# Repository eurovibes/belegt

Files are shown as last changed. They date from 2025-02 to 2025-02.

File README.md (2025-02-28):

<!-- SPDX-FileCopyrightText: 2025 Benedikt Spranger <b.spranger@linutronix.de> -->
<!-- SPDX-License-Identifier: CERN-OHL-S-2.0 -->


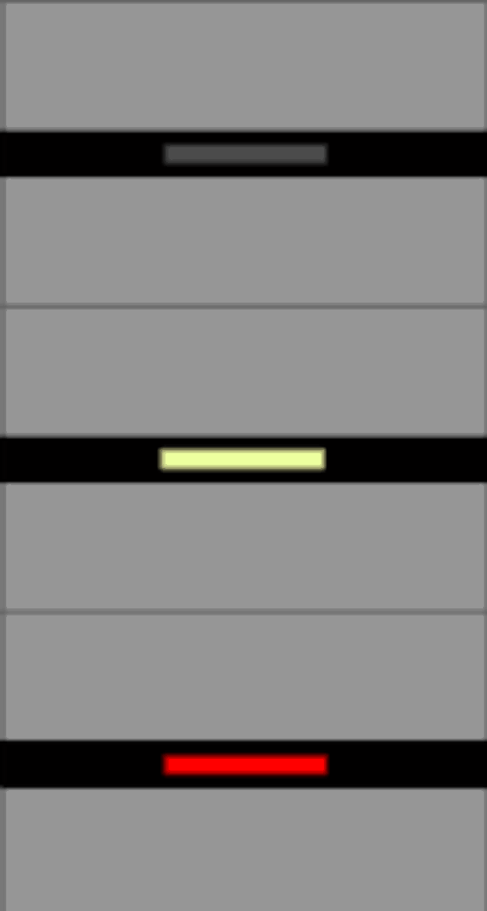
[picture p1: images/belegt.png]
Belegt logo


# Belegt - A model train track occupation sensor

## License rules

belegt is provided under the terms of the CERN-OHL-S license
version 2 as provided in the LICENSES/CERN-OHL-S-2.0 file.

Instead of adding license boilerplates to the individual files,
belegt uses SPDX license identifiers, which are machine parseable
and considered legaly equivalent.

The SPDX license identifier in belegt shall be added at the first
possible line in a file which can contain a comment. This is normally the
first line except for scripts. Scripts require the #!PATH_TO_INTERPRETER tag
in the first line; place the SPDX identifier into the second line.

The SPDX license identifier is added in form of a comment.

## Copyright and License

> Copyright Benedikt Spranger 2023.
> This source describes Open Hardware and is licensed under the CERNOHL-S v2.
> You may redistribute and modify this source and make products using it
> under the terms of the CERN-OHL-S v2 (https://ohwr.org/cern ohl s v2.txt ).
> This source is distributed WITHOUT ANY EXPRESS OR IMPLIED WARRANTY, INCLUDING
> OF MERCHANTABILITY, SATISFACTORY QUALITY AND FITNESS FOR A PARTICULAR PURPOSE.
> Please see the CERN-OHL-S v2 for applicable conditions.
> Source location: https://github.com/eurovibes/belegt
> As per CERN-OHL-S v2 section 4, should You produce hardware based
> on this source, You must where practicable maintain the Source Location
> visible on the external case of the belegt or other products you
> make using this source.

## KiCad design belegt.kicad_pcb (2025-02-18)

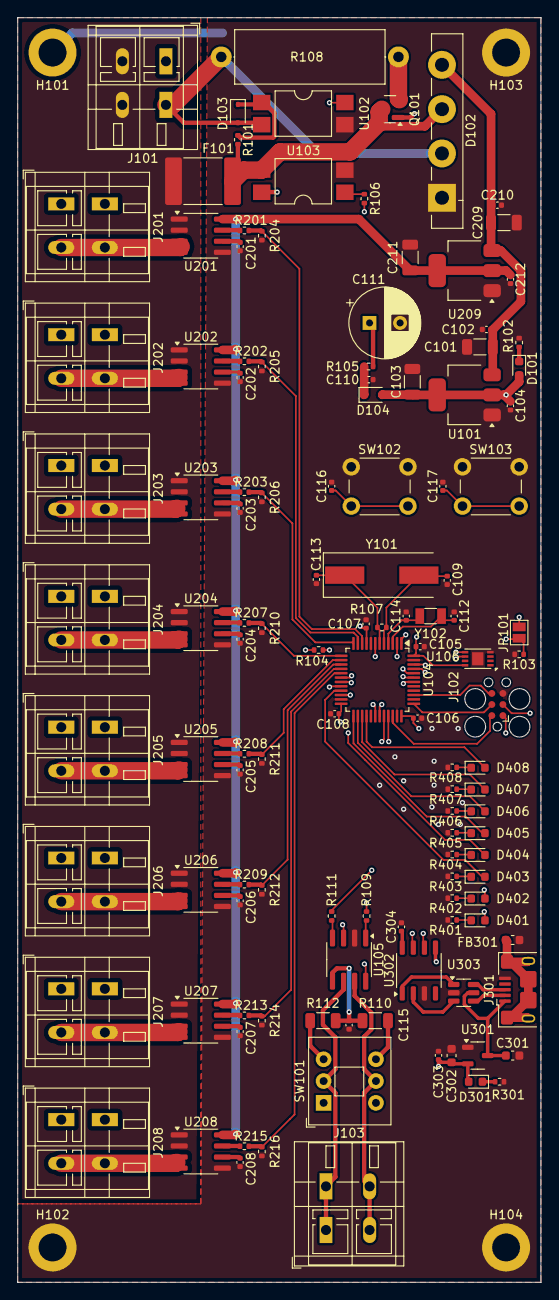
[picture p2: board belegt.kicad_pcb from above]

Board: 4 copper layers, 60.0 x 145.0 mm, 126 parts (0 on the bottom side), 97 nets.

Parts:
C101, C103, C209, C211: 10µ; C_1206_3216Metric
C102, C104, C105, C106, C107, C108, C110, C116, C117, C201, C202, C203, C204, C205, C206, C207, C208, C210, C212, C303, C304: 100n; C_0402_1005Metric
C109, C113: 20p; C_0402_1005Metric
C111: 1F; CP_Radial_D8.0mm_P3.50mm
C112, C114: 12p; C_0402_1005Metric
C115: 4n7; C_0402_1005Metric
C301, C302: 1µ; C_0603_1608Metric
D101, D301, D401, D402, D403, D404, D405, D406, D407, D408: LED; LED_0603_1608Metric
D102: GBU8A; Diode_Bridge_Vishay_GBU
D103, D104: 1N4148WS; D_SOD-323
F101: Polyfuse_Small; Fuse_2920_7451Metric
FB301: FerriteBead_Small; L_0603_1608Metric
H101, H102, H103, H104: MountingHole_3.2mm_M3_ISO14580_Pad
J101: Power IN; TerminalBlock_WAGO_236-402_1x02_P5.00mm_45Degree
J102: Debug; Tag-Connect_TC2030-IDC-FP_2x03_P1.27mm_Vertical
J103: CAN; TerminalBlock_WAGO_236-402_1x02_P5.00mm_45Degree
J201: track1; TerminalBlock_WAGO_236-402_1x02_P5.00mm_45Degree
J202: track5; TerminalBlock_WAGO_236-402_1x02_P5.00mm_45Degree
J203: track7; TerminalBlock_WAGO_236-402_1x02_P5.00mm_45Degree
J204: track2; TerminalBlock_WAGO_236-402_1x02_P5.00mm_45Degree
J205: track6; TerminalBlock_WAGO_236-402_1x02_P5.00mm_45Degree
J206: track8; TerminalBlock_WAGO_236-402_1x02_P5.00mm_45Degree
J207: track3; TerminalBlock_WAGO_236-402_1x02_P5.00mm_45Degree
J208: track4; TerminalBlock_WAGO_236-402_1x02_P5.00mm_45Degree
J301: USB_B_Micro; USB_Micro-B_Amphenol_10118193-0001LF_Horizontal
JP101: Boot0; SolderJumper-2_P1.3mm_Open_Pad1.0x1.5mm
Q101: BC860; SOT-23
R101, R102, R104, R105, R106, R301, R401, R402, R403, R404, R405, R406, R407, R408: 1k; R_0402_1005Metric
R103, R204, R205, R206, R210, R211, R212, R214, R216: 10k; R_0402_1005Metric
R107: 1M; R_0402_1005Metric
R108: 100; R_Axial_DIN0617_L17.0mm_D6.0mm_P20.32mm_Horizontal
R109, R111: 100; R_0402_1005Metric
R110, R112: 60; R_1206_3216Metric
R201, R202, R203, R207, R208, R209, R213, R215: 2k; R_0402_1005Metric
SW101: Term; SW_Push_2P2T_Toggle_CK_PVA2xxH1xxxxxxV2
SW102: Reset; SW_PUSH_6mm
SW103: User; SW_PUSH_6mm
U101: AMS1117-3.3; SOT-223-3_TabPin2
U102, U103: EL817S1(C)(TU)-F; SMDIP-4_W9.53mm
U104: STM32F103CBTx; LQFP-48_7x7mm_P0.5mm
U105: TJA1042T; SOIC-8_3.9x4.9mm_P1.27mm
U106: ATECC608B-MAVDA-S; DFN-8-1EP_3x2mm_P0.5mm_EP1.3x1.5mm
U201, U202, U203, U204, U205, U206, U207, U208: ACS712ELCTR-05B; SOIC-8_3.9x4.9mm_P1.27mm
U209: AMS1117-5.0; SOT-223-3_TabPin2
U301: XC6206P332MR; SOT-23-3
U302: CH340N; SOP-8_3.9x4.9mm_P1.27mm
U303: USBLC6-2SC6; SOT-23-6
Y101: 8MHz; Crystal_SMD_HC49-SD
Y102: 32k; Crystal_SMD_3215-2Pin_3.2x1.5mm

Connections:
+3V3: C103.1, C104.1, C105.1, C106.1, C107.1, C108.1, D101.2 (A), D104.2 (A), J102.1 (VCC), JP101.2 (B), R104.2, U101.2 (VO), U104.9 (VDDA), U104.24 (VDD), U104.36 (VDD), U104.48 (VDD), U105.3 (VCC), U106.8 (VCC)
+5V: C211.1, C212.1, U201.8 (VCC), U202.8 (VCC), U203.8 (VCC), U204.8 (VCC), U205.8 (VCC), U206.8 (VCC), U207.8 (VCC), U208.8 (VCC), U209.2 (VO)
+15V: C101.1, C102.1, C209.1, C210.1, D102.4 (-), U101.3 (VI), U209.3 (VI)
+BATT: C111.1, R105.2, U104.1 (VBAT)
+VSW: F101.1, J101.2, U201.1 (IP+), U201.2 (IP+), U202.1 (IP+), U202.2 (IP+), U203.1 (IP+), U203.2 (IP+), U204.1 (IP+), U204.2 (IP+), U205.1 (IP+), U205.2 (IP+), U206.1 (IP+), U206.2 (IP+), U207.1 (IP+), U207.2 (IP+), U208.1 (IP+), U208.2 (IP+)
-VSW: D102.2, D103.2 (A), J101.1, J201.1, J202.1, J203.1, J204.1, J205.1, J206.1, J207.1, J208.1, R108.2, U102.2
/ACK: R106.1, U104.19 (PB1)
/BOOT0: JP101.1 (A), R103.1, U104.44 (BOOT0)
/BTN: C117.1, SW103.2, U104.2 (PC13)
/CAN_RX: R111.2, U104.33 (PA12)
/CAN_TX: R109.2, U104.32 (PA11)
/LED/LED1: D401.2 (A), U104.45 (PB8)
/LED/LED2: D402.2 (A), U104.46 (PB9)
/LED/LED3: D403.2 (A), U104.21 (PB10)
/LED/LED4: D404.2 (A), U104.22 (PB11)
/LED/LED5: D405.2 (A), U104.25 (PB12)
/LED/LED6: D406.2 (A), U104.26 (PB13)
/LED/LED7: D407.2 (A), U104.27 (PB14)
/LED/LED8: D408.2 (A), U104.28 (PB15)
/PROBE: R104.1, U102.4, U104.18 (PB0)
/SCL: U104.42 (PB6), U106.6 (SCL)
/SDA: U104.43 (PB7), U106.5 (SDA)
/SENSE0: R201.2, R204.2, U104.10 (PA0)
/SENSE1: R202.2, R205.2, U104.11 (PA1)
/SENSE2: R203.2, R206.2, U104.12 (PA2)
/SENSE3: R207.2, R210.2, U104.13 (PA3)
/SENSE4: R208.2, R211.2, U104.14 (PA4)
/SENSE5: R209.2, R212.2, U104.15 (PA5)
/SENSE6: R213.2, R214.2, U104.16 (PA6)
/SENSE7: R215.2, R216.2, U104.17 (PA7)
/STB: U104.20 (PB2), U105.8 (STB)
/SWCLK: J102.4 (SWCLK), U104.37 (PA14)
/SWDIO: J102.2 (SWDIO), U104.34 (PA13)
/SWO: J102.6 (SWO), U104.39 (PB3)
/Serial/RXD: U104.30 (PA9), U302.7 (RXD)
/Serial/TXD: U104.31 (PA10), U302.6 (TXD)
/~RST: C116.1, J102.3 (~RESET), SW102.2, U104.7 (NRST)
GND: C101.2, C102.2, C103.2, C104.2, C105.2, C106.2, C107.2, C108.2, C109.1, C110.2, C111.2, C112.1, C113.1, C114.1, C115.1, C116.2, C117.2, C201.2, C202.2, C203.2, C204.2, C205.2, C206.2, C207.2, C208.2, C209.2, C210.2, C211.2, C212.2, C301.2, C302.2, C303.2, C304.2, D102.1 (+), FB301.2, H101.1, H102.1, H103.1, H104.1, J102.5 (GND), J301.5 (GND), R102.2, R103.2, R204.1, R205.1, R206.1, R210.1, R211.1, R212.1, R214.1, R216.1, R301.1, R401.2, R402.2, R403.2, R404.2, R405.2, R406.2, R407.2, R408.2, SW102.1, SW103.1, U101.1 (GND), U102.3, U103.2, U104.8 (VSSA), U104.23 (VSS), U104.35 (VSS), U104.47 (VSS), U105.2 (GND), U106.4 (GND), U106.9 (EP), U201.5 (GND), U202.5 (GND), U203.5 (GND), U204.5 (GND), U205.5 (GND), U206.5 (GND), U207.5 (GND), U208.5 (GND), U209.1 (GND), U301.1 (GND), U302.3 (GND), U303.2 (GND)
unnamed: D101.1 (K), R102.1
unnamed: D103.1 (K), R101.1, U102.1
unnamed: C110.1, D104.1 (K), R105.1
unnamed: C302.1, C303.1, D301.2 (A), U301.2 (VO), U302.5 (VCC)
unnamed: D301.1 (K), R301.2
unnamed: D401.1 (K), R401.1
unnamed: D402.1 (K), R402.1
unnamed: D403.1 (K), R403.1
unnamed: D404.1 (K), R404.1
unnamed: D405.1 (K), R405.1
unnamed: D406.1 (K), R406.1
unnamed: D407.1 (K), R407.1
unnamed: D408.1 (K), R408.1
unnamed: J103.1, SW101.2 (B), U105.6 (CANL)
unnamed: J103.2, SW101.5 (B), U105.7 (CANH)
unnamed: J201.2, U201.3 (IP-), U201.4 (IP-)
unnamed: J202.2, U202.3 (IP-), U202.4 (IP-)
unnamed: J203.2, U203.3 (IP-), U203.4 (IP-)
unnamed: J204.2, U204.3 (IP-), U204.4 (IP-)
unnamed: J205.2, U205.3 (IP-), U205.4 (IP-)
unnamed: J206.2, U206.3 (IP-), U206.4 (IP-)
unnamed: J207.2, U207.3 (IP-), U207.4 (IP-)
unnamed: J208.2, U208.3 (IP-), U208.4 (IP-)
unnamed: J301.3 (D+), U303.6 (I/O1)
unnamed: J301.2 (D-), U303.4 (I/O2)
unnamed: FB301.1, J301.6 (Shield)
unnamed: C301.1, J301.1 (VBUS), U301.3 (VI), U303.5 (VBUS)
unnamed: Q101.1 (B), U103.4
unnamed: D102.3, F101.2, Q101.3 (C), R101.2, U103.3
unnamed: Q101.2 (E), R108.1
unnamed: R106.2, U103.1
unnamed: R110.1, SW101.6 (C)
unnamed: R112.2, SW101.3 (C)
unnamed: C112.2, U104.3 (PC14), Y102.2
unnamed: C114.2, U104.4 (PC15), Y102.1
unnamed: C109.2, R107.1, U104.5 (PD0), Y101.2
unnamed: C113.2, R107.2, U104.6 (PD1), Y101.1
unnamed: R111.1, U105.4 (RXD)
unnamed: C115.2, R110.2, R112.1, U105.5 (SPLIT)
unnamed: R109.1, U105.1 (TXD)
unnamed: C201.1, U201.6 (FILTER)
unnamed: R201.1, U201.7 (VIOUT)
unnamed: C202.1, U202.6 (FILTER)
unnamed: R202.1, U202.7 (VIOUT)
unnamed: C203.1, U203.6 (FILTER)
unnamed: R203.1, U203.7 (VIOUT)
unnamed: C204.1, U204.6 (FILTER)
unnamed: R207.1, U204.7 (VIOUT)
unnamed: C205.1, U205.6 (FILTER)
unnamed: R208.1, U205.7 (VIOUT)
unnamed: C206.1, U206.6 (FILTER)
unnamed: R209.1, U206.7 (VIOUT)
unnamed: C207.1, U207.6 (FILTER)
unnamed: R213.1, U207.7 (VIOUT)
unnamed: C208.1, U208.6 (FILTER)
unnamed: R215.1, U208.7 (VIOUT)
unnamed: U302.1 (UD+), U303.1 (I/O1)
unnamed: U302.2 (UD-), U303.3 (I/O2)
unnamed: C304.1, U302.8 (V3)

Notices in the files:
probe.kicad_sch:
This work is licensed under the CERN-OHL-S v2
